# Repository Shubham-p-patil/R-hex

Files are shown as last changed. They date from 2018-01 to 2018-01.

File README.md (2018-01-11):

# R-hex
Negotiating difficult terrains has always been a challenging task for wheeled robots. To solve this issue, man has been trying to design various legged robots, taking inspiration from nature. Out of all these legged robots, six legged robots are the most common ones, since 6 legs have an edge over other legged robots considering their stability. In hexapods, generally a tripod gait is in used in which 2 sets of legs(3 each ) are alternatively on the ground. This hexapod is our attempt to tackle the same issue of all terrain driving capabilities. Instead of normal legs we have used C-shaped legs which have an added advantage of climbing obstacles, pretty taller than itself.

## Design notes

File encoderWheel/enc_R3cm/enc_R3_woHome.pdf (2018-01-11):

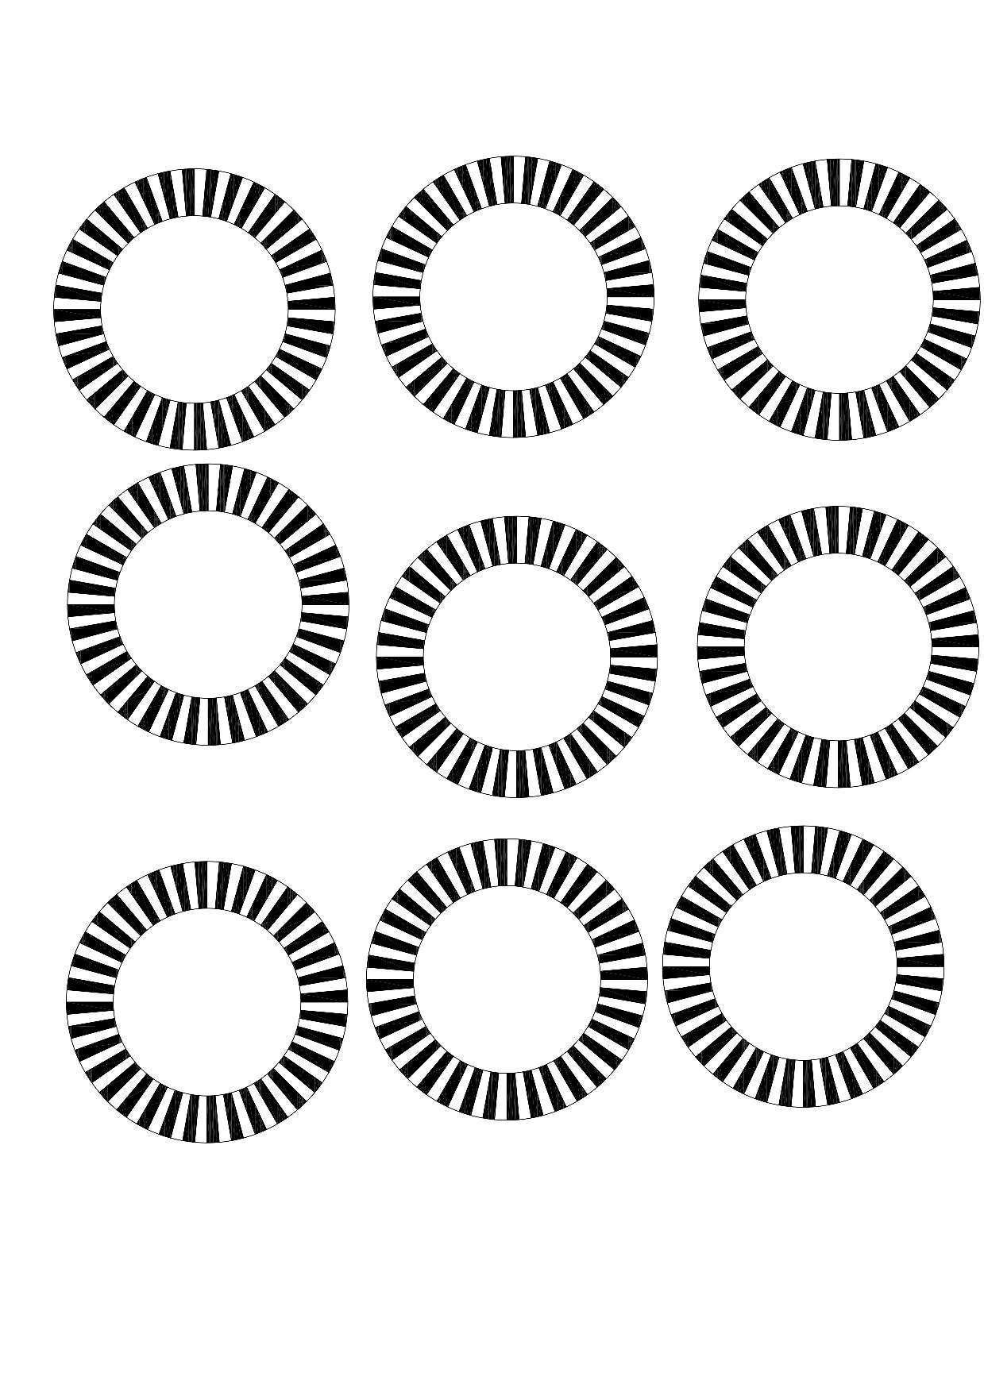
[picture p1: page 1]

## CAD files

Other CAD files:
encoderWheel/enc_R2.5cm/enc_R2.5_wHome.dwg
encoderWheel/enc_R3cm/enc_R3_wHome.dwg
encoderWheel/newR2.5/newR2.5.dwg

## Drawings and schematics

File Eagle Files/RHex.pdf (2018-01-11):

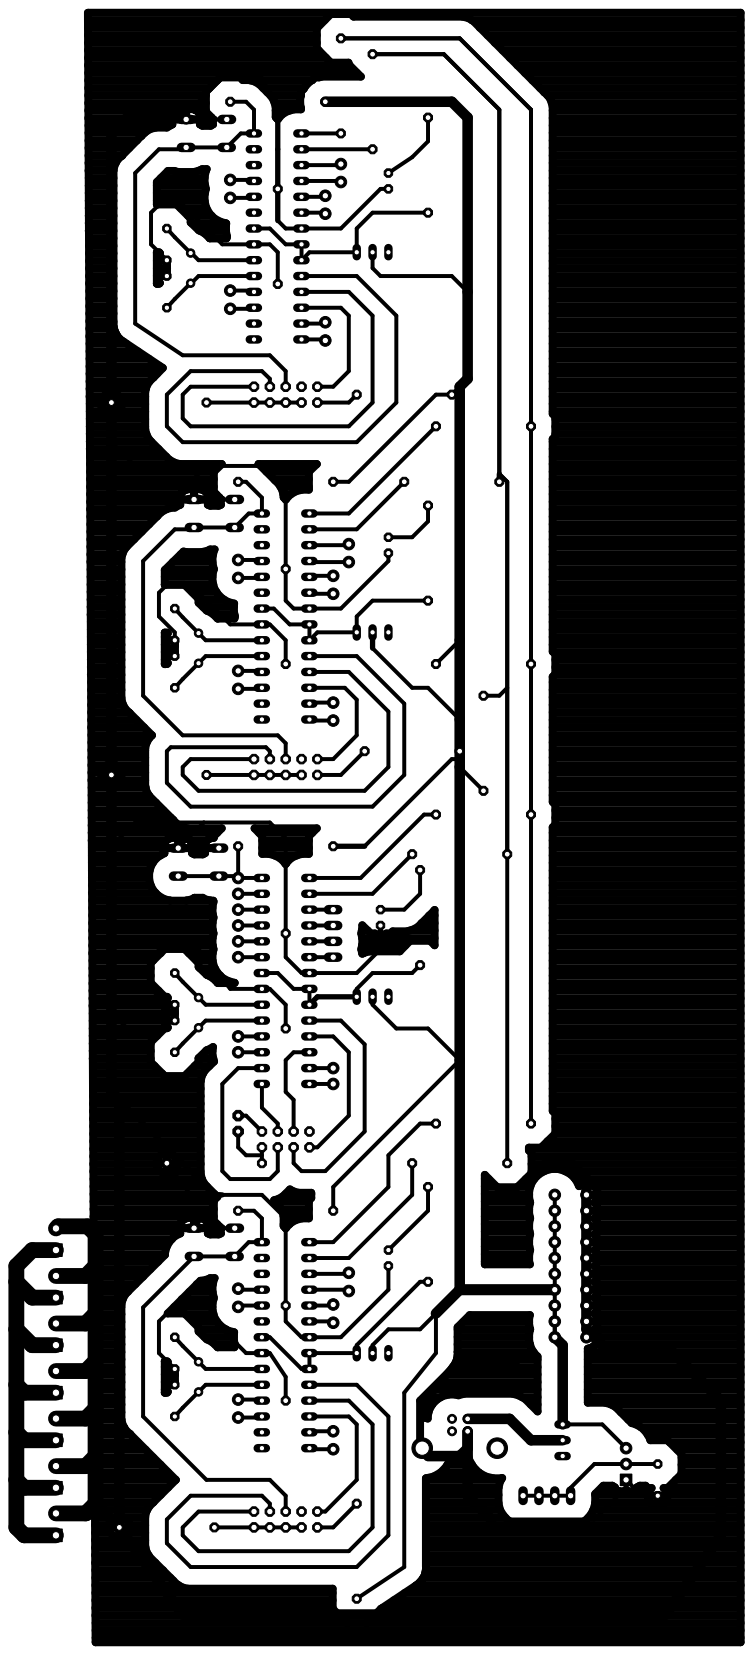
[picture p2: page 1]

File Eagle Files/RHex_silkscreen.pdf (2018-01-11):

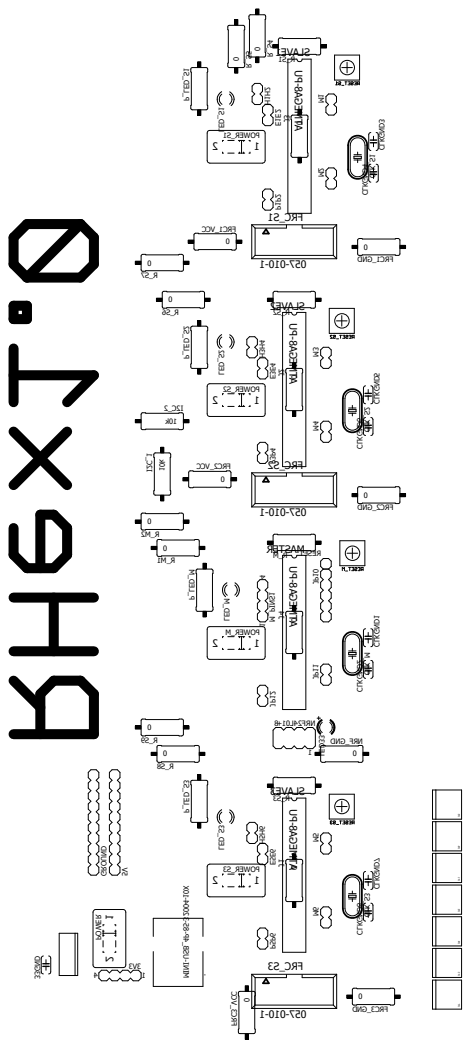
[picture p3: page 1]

057-010-1 ATMEGA8-PU ATMEGA8-PU ATMEGA8-PU ATMEGA8-PU MINI-USB_4P-85-32004-10X 0 0 0 0 0 0 0 0 0 0 0 0 0 0 0 0 0 0 0 10k

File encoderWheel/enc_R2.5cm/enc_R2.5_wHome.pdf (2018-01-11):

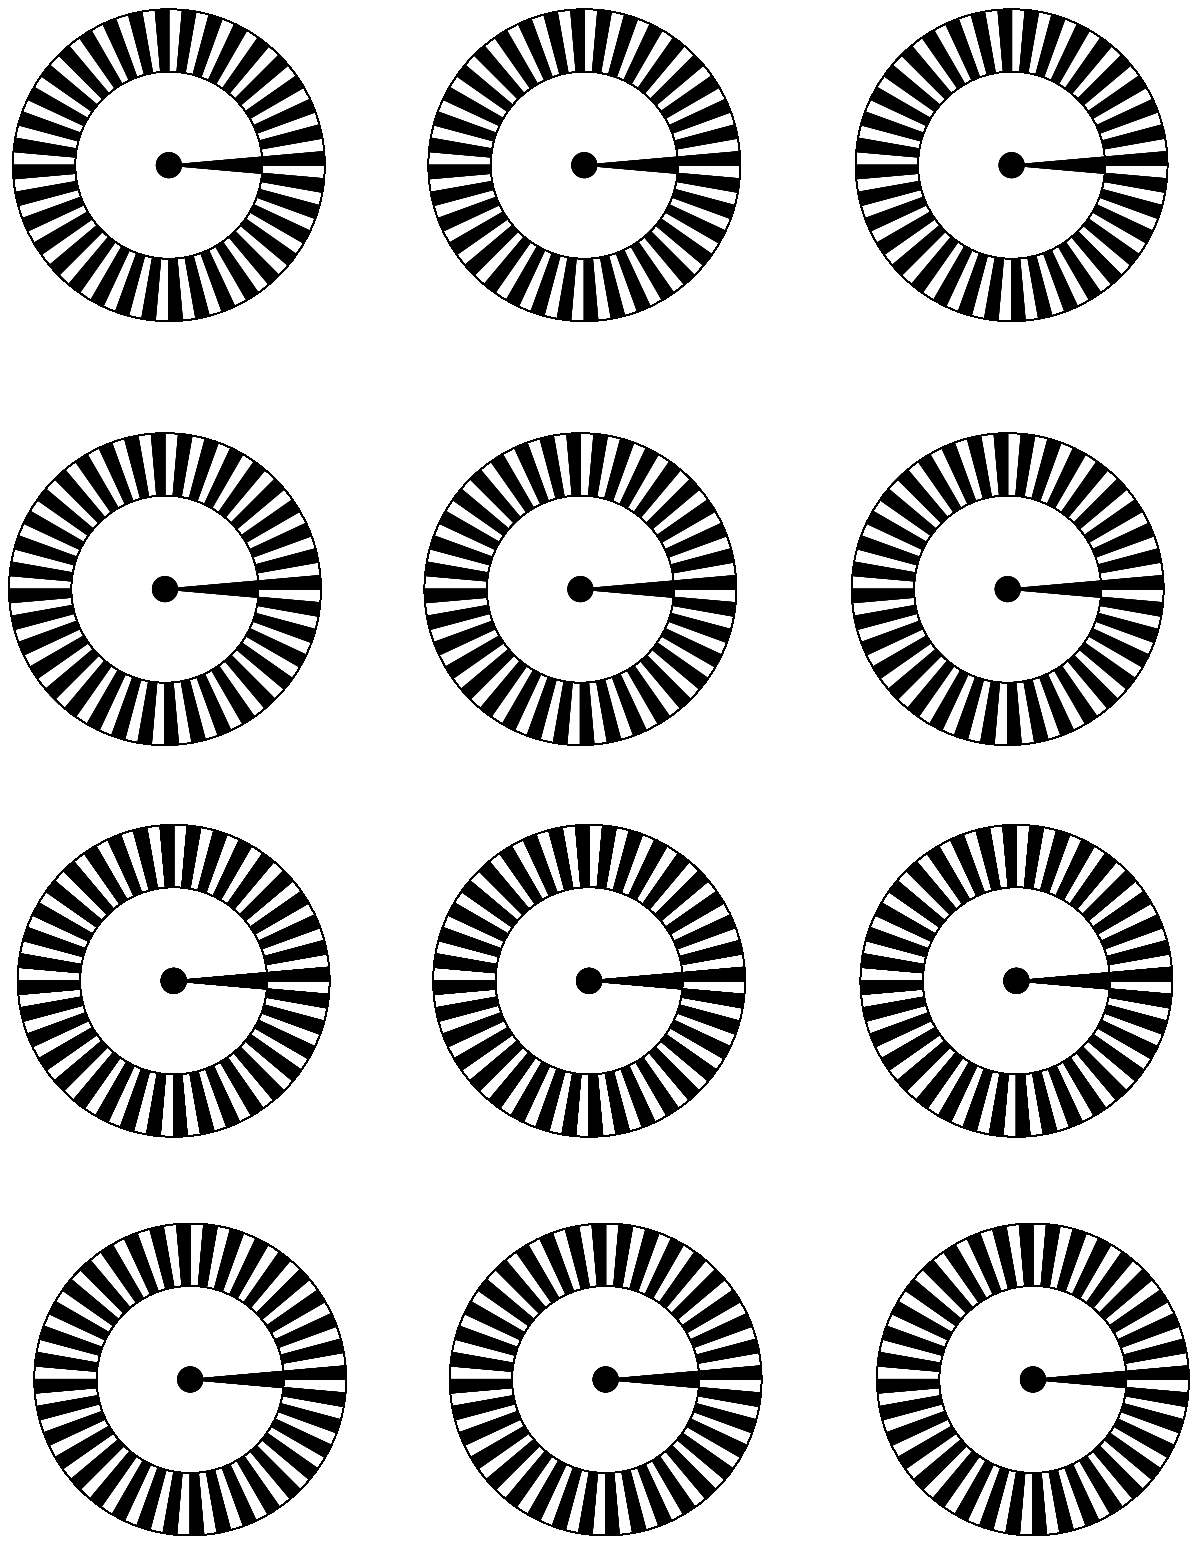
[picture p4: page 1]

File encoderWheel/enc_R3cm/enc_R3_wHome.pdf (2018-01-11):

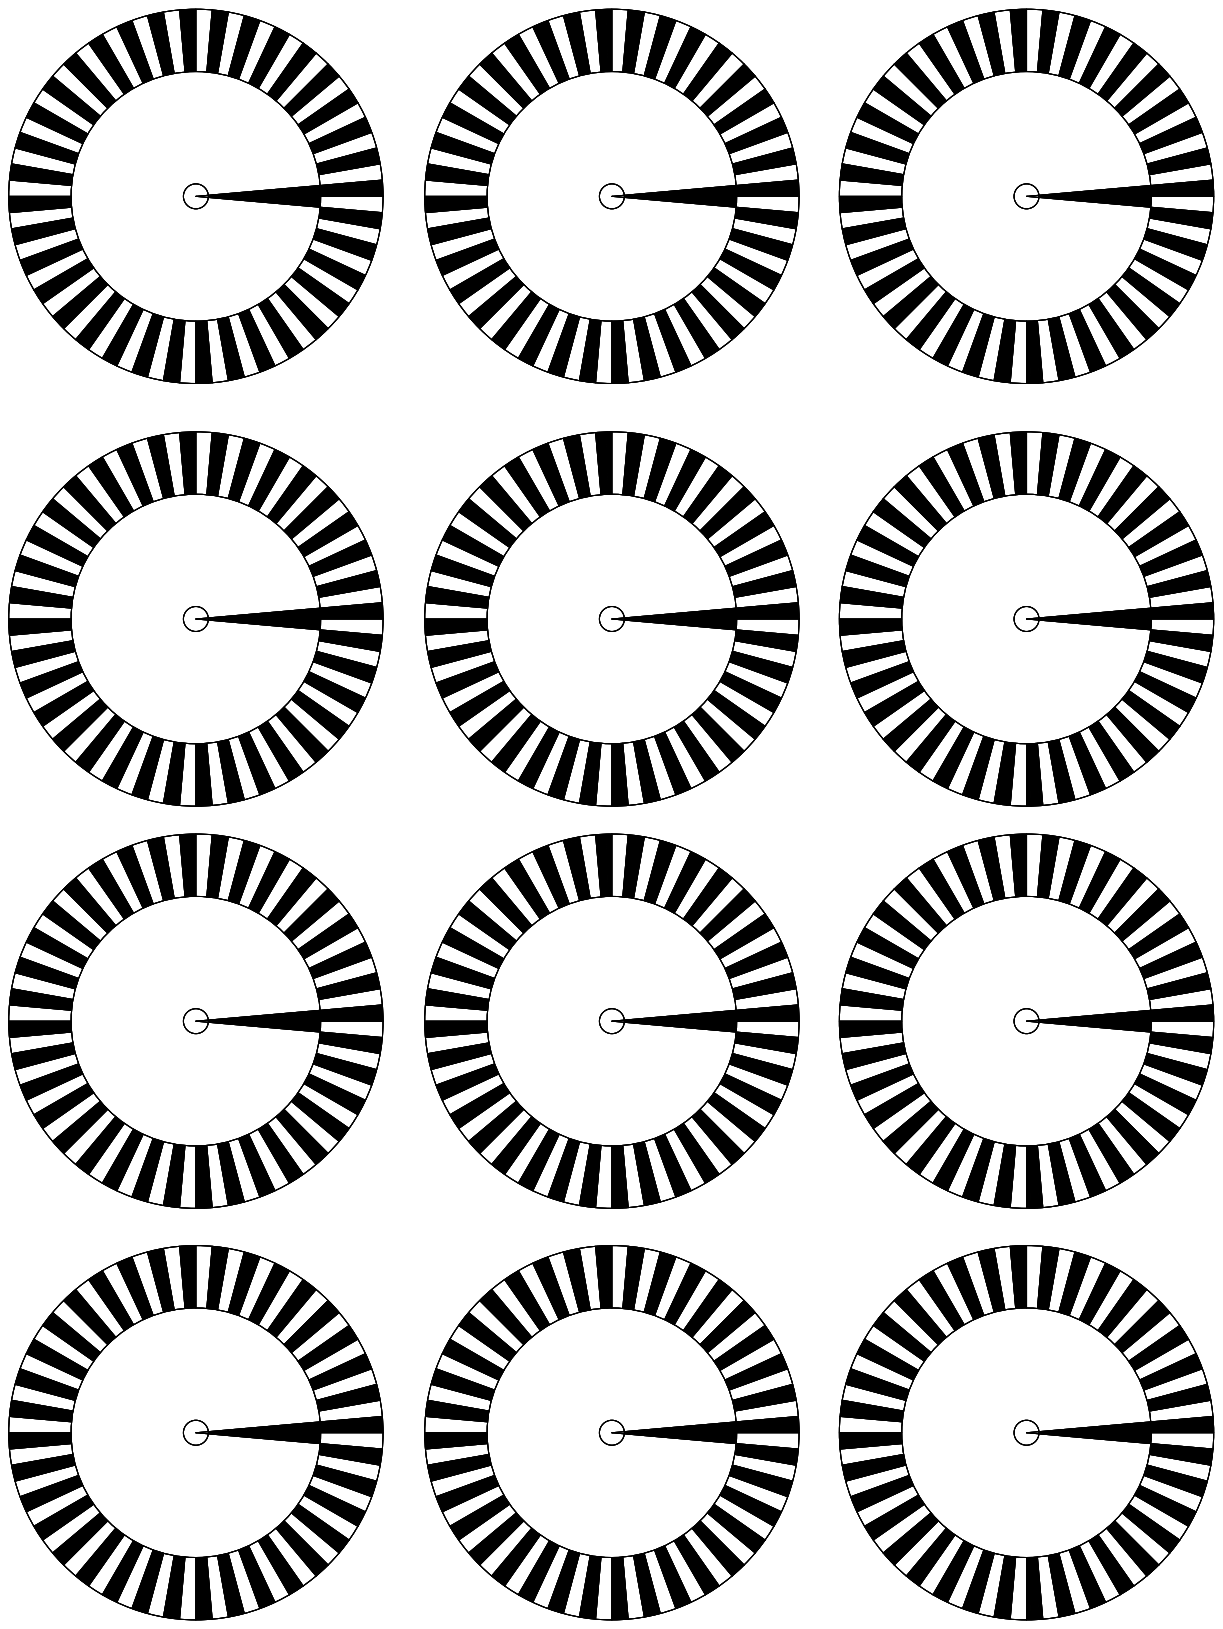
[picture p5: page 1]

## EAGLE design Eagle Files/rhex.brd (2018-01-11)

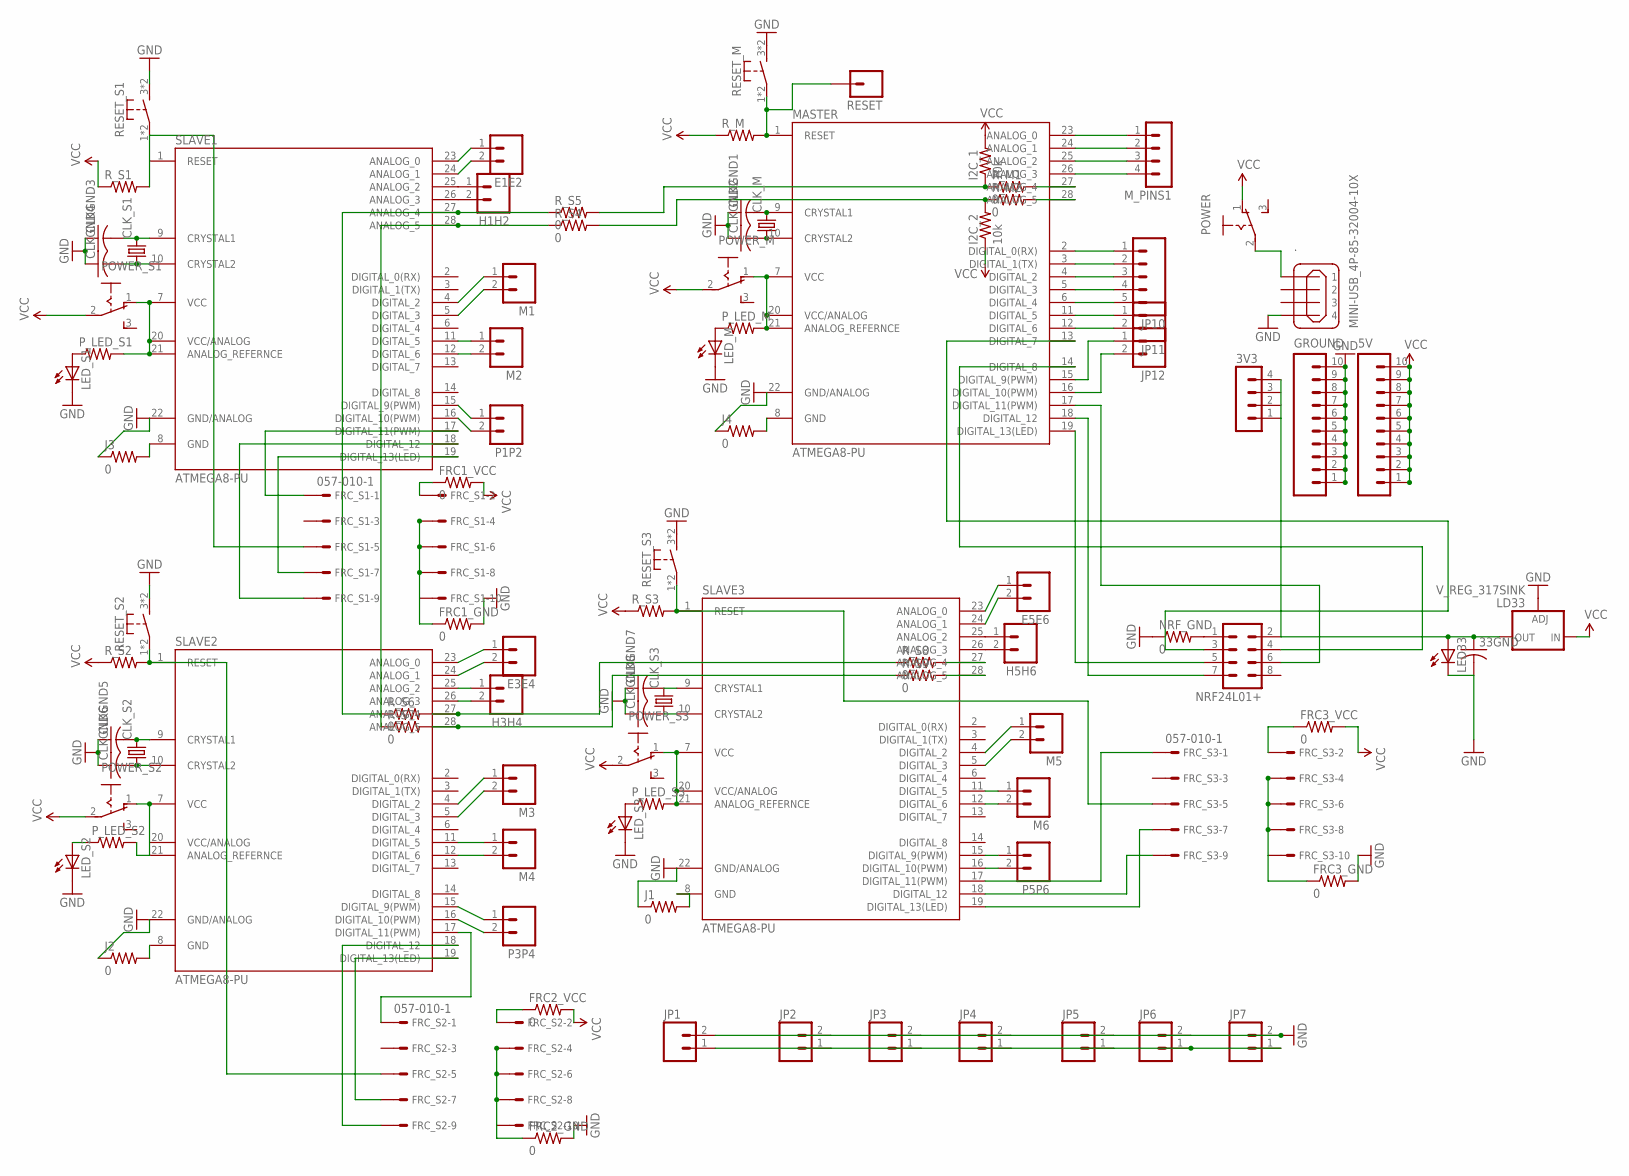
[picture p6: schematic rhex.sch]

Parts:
3V3: MA04-1
5V: M10SILK_FEMALE_PTH; 1X10
33GND: C-US050-024X044; C050-024X044
.: MINI-USB_4P-85-32004-10X; 85-32004-10X
CLKGND1, CLKGND2, CLKGND3, CLKGND4, CLKGND5, CLKGND6, CLKGND7, CLKGND8: C-US050-024X044; C050-024X044
CLK_M: CRYSTALHC49U-V; HC49U-V
CLK_S1, CLK_S2, CLK_S3: CRYSTALHC49U-V; HC49U-V
E1E2, E3E4, E5E6: M02LOCK; 1X02_LOCK
FRC1_GND, FRC1_VCC, FRC2_GND, FRC2_VCC, FRC3_GND, FRC3_VCC: 0; 0411/15
FRC_S1, FRC_S2, FRC_S3: 057-010-1
GROUND: M10SILK_FEMALE_PTH; 1X10
H1H2, H3H4, H5H6: M02LOCK; 1X02_LOCK
I2C_1, I2C_2: 10k; 0411/15
J1, J2, J3, J4: 0; 0411/15
JP1, JP2, JP3, JP4, JP5, JP6, JP7: M023.5MM; SCREWTERMINAL-3.5MM-2
JP10: M05PTH; 1X05
JP11, JP12: M02PTH; 1X02
LD33: V_REG_317SINK; TO220-ADJ
LED33: LED3MM
LED_M: LED3MM
LED_S1, LED_S2, LED_S3: LED3MM
M1, M2, M3, M4, M5, M6: M02LOCK; 1X02_LOCK
MASTER: ATMEGA8-PU; DIL28-3
M_PINS1: MA04-1
NRF24L01+: MA04-2
NRF_GND: 0; 0411/15
P1P2, P3P4, P5P6: M02LOCK; 1X02_LOCK
POWER: M251
POWER_M: M251
POWER_S1, POWER_S2, POWER_S3: M251
P_LED_M: R-US_0411/15; 0411/15
P_LED_S1, P_LED_S2, P_LED_S3: R-US_0411/15; 0411/15
RESET: M01PTH; 1X01
RESET_M: SW-TACTILE-6X6; SW6X6
RESET_S1, RESET_S2, RESET_S3: SW-TACTILE-6X6; SW6X6
R_M: R-US_0411/15; 0411/15
R_M1, R_M2: 0; 0411/15
R_S1, R_S2, R_S3: R-US_0411/15; 0411/15
R_S4, R_S5, R_S6, R_S7, R_S8, R_S9: 0; 0411/15
SLAVE1, SLAVE2, SLAVE3: ATMEGA8-PU; DIL28-3

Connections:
3V3: 3V3.1, 3V3.4, 33GND.1, LD33.OUT, LED33.A, NRF24L01+.2
12V: JP1.1, JP2.1, JP3.1, JP4.1, JP5.1, JP6.1, JP7.1
GND: 33GND.2, ..4, CLKGND1.1, CLKGND2.1, CLKGND3.1, CLKGND4.1, CLKGND5.1, CLKGND6.1, CLKGND7.1, CLKGND8.1, FRC1_GND.2, FRC2_GND.2, FRC3_GND.2, GROUND.1, GROUND.2, GROUND.3, GROUND.4, GROUND.5, GROUND.6, GROUND.7, GROUND.8, GROUND.9, GROUND.10, J1.1, J2.1, J3.1, J4.1, JP1.2, JP2.2, JP3.2, JP4.2, JP5.2, JP6.2, JP7.2, LD33.ADJ, LED33.K (C), LED_M.K (C), LED_S1.K (C), LED_S2.K (C), LED_S3.K (C), MASTER.22 (GND/ANALOG), NRF_GND.1, RESET_M.3 (S1), RESET_M.4 (S1), RESET_S1.3 (S1), RESET_S1.4 (S1), RESET_S2.3 (S1), RESET_S2.4 (S1), RESET_S3.3 (S1), RESET_S3.4 (S1), SLAVE1.22 (GND/ANALOG), SLAVE2.22 (GND/ANALOG), SLAVE3.22 (GND/ANALOG)
unnamed: CLKGND1.2, CLK_M.2, MASTER.9 (CRYSTAL1)
unnamed: CLKGND2.2, CLK_M.1, MASTER.10 (CRYSTAL2)
unnamed: MASTER.1 (RESET), RESET.1, RESET_M.1, RESET_M.2 (P1), R_M.2
unnamed: FRC_S2.1, SLAVE2.17 (DIGITAL_11(PWM))
unnamed: FRC_S3.5, RESET_S3.1, RESET_S3.2 (P1), R_S3.2, SLAVE3.1 (RESET)
unnamed: FRC_S2.5, RESET_S2.1, RESET_S2.2 (P1), R_S2.2, SLAVE2.1 (RESET)
unnamed: M3.1, SLAVE2.4 (DIGITAL_2)
unnamed: MASTER.19 (DIGITAL_13(LED)), NRF24L01+.5
unnamed: MASTER.18 (DIGITAL_12), NRF24L01+.7
unnamed: MASTER.17 (DIGITAL_11(PWM)), NRF24L01+.6
unnamed: R_S5.1, R_S6.1, SLAVE1.27 (ANALOG_4)
unnamed: R_S4.1, R_S7.1, SLAVE1.28 (ANALOG_5)
unnamed: M1.1, SLAVE1.4 (DIGITAL_2)
unnamed: M1.2, SLAVE1.5 (DIGITAL_3)
unnamed: M3.2, SLAVE2.5 (DIGITAL_3)
unnamed: M5.1, SLAVE3.4 (DIGITAL_2)
unnamed: M2.1, SLAVE1.11 (DIGITAL_5)
unnamed: MASTER.13 (DIGITAL_7), NRF24L01+.3
unnamed: M5.2, SLAVE3.5 (DIGITAL_3)
unnamed: M4.1, SLAVE2.11 (DIGITAL_5)
unnamed: M4.2, SLAVE2.12 (DIGITAL_6)
unnamed: M6.1, SLAVE3.11 (DIGITAL_5)
unnamed: M6.2, SLAVE3.12 (DIGITAL_6)
unnamed: M2.2, SLAVE1.12 (DIGITAL_6)
unnamed: JP10.1, MASTER.2 (DIGITAL_0(RX))
unnamed: I2C_2.2, R_M2.1, R_S4.2
unnamed: NRF24L01+.1, NRF_GND.2
unnamed: FRC_S2.7, SLAVE2.19 (DIGITAL_13(LED))
unnamed: E1E2.1, SLAVE1.23 (ANALOG_0)
unnamed: E1E2.2, SLAVE1.24 (ANALOG_1)
unnamed: E3E4.1, SLAVE2.23 (ANALOG_0)
unnamed: E3E4.2, SLAVE2.24 (ANALOG_1)
unnamed: E5E6.1, SLAVE3.23 (ANALOG_0)
unnamed: E5E6.2, SLAVE3.24 (ANALOG_1)
unnamed: CLKGND3.2, CLK_S1.2, SLAVE1.9 (CRYSTAL1)
unnamed: CLKGND4.2, CLK_S1.1, SLAVE1.10 (CRYSTAL2)
unnamed: CLKGND5.2, CLK_S2.2, SLAVE2.9 (CRYSTAL1)
unnamed: P3P4.1, SLAVE2.15 (DIGITAL_9(PWM))
unnamed: P3P4.2, SLAVE2.16 (DIGITAL_10(PWM))
unnamed: CLKGND6.2, CLK_S2.1, SLAVE2.10 (CRYSTAL2)
unnamed: CLKGND7.2, CLK_S3.2, SLAVE3.9 (CRYSTAL1)
unnamed: CLKGND8.2, CLK_S3.1, SLAVE3.10 (CRYSTAL2)
unnamed: FRC_S2.9, SLAVE2.18 (DIGITAL_12)
unnamed: ..1, POWER.2
unnamed: FRC_S3.1, SLAVE3.17 (DIGITAL_11(PWM))
unnamed: POWER_S1.1 (O), P_LED_S1.2, SLAVE1.7 (VCC), SLAVE1.20 (VCC/ANALOG), SLAVE1.21 (ANALOG_REFERNCE)
unnamed: FRC_S3.7, SLAVE3.19 (DIGITAL_13(LED))
unnamed: FRC_S3.9, SLAVE3.18 (DIGITAL_12)
unnamed: FRC_S1.7, SLAVE1.19 (DIGITAL_13(LED))
unnamed: FRC_S1.9, SLAVE1.18 (DIGITAL_12)
unnamed: FRC_S1.1, SLAVE1.17 (DIGITAL_11(PWM))
unnamed: P1P2.1, SLAVE1.15 (DIGITAL_9(PWM))
unnamed: POWER_S2.1 (O), P_LED_S2.2, SLAVE2.7 (VCC), SLAVE2.20 (VCC/ANALOG), SLAVE2.21 (ANALOG_REFERNCE)
unnamed: MASTER.7 (VCC), MASTER.20 (VCC/ANALOG), MASTER.21 (ANALOG_REFERNCE), POWER_M.1 (O), P_LED_M.2
unnamed: POWER_S3.1 (O), P_LED_S3.2, SLAVE3.7 (VCC), SLAVE3.20 (VCC/ANALOG), SLAVE3.21 (ANALOG_REFERNCE)
unnamed: P1P2.2, SLAVE1.16 (DIGITAL_10(PWM))
unnamed: P5P6.1, SLAVE3.15 (DIGITAL_9(PWM))
unnamed: P5P6.2, SLAVE3.16 (DIGITAL_10(PWM))
unnamed: H5H6.1, SLAVE3.25 (ANALOG_2)
unnamed: H5H6.2, SLAVE3.26 (ANALOG_3)
unnamed: H1H2.1, SLAVE1.25 (ANALOG_2)
unnamed: H1H2.2, SLAVE1.26 (ANALOG_3)
unnamed: H3H4.1, SLAVE2.25 (ANALOG_2)
unnamed: H3H4.2, SLAVE2.26 (ANALOG_3)
unnamed: LED_S1.A, P_LED_S1.1
unnamed: LED_M.A, P_LED_M.1
unnamed: LED_S3.A, P_LED_S3.1
unnamed: FRC2_GND.1, FRC_S2.4, FRC_S2.6, FRC_S2.8, FRC_S2.10
unnamed: LED_S2.A, P_LED_S2.1
unnamed: JP10.2, MASTER.3 (DIGITAL_1(TX))
unnamed: JP10.3, MASTER.4 (DIGITAL_2)
unnamed: JP10.4, MASTER.5 (DIGITAL_3)
unnamed: JP10.5, MASTER.6 (DIGITAL_4)
unnamed: JP11.1, MASTER.11 (DIGITAL_5)
unnamed: JP11.2, MASTER.12 (DIGITAL_6)
unnamed: JP12.1, MASTER.15 (DIGITAL_9(PWM))
unnamed: JP12.2, MASTER.16 (DIGITAL_10(PWM))
unnamed: MASTER.14 (DIGITAL_8), NRF24L01+.4
unnamed: MASTER.23 (ANALOG_0), M_PINS1.1
unnamed: MASTER.24 (ANALOG_1), M_PINS1.2
unnamed: MASTER.25 (ANALOG_2), M_PINS1.3
unnamed: MASTER.26 (ANALOG_3), M_PINS1.4
unnamed: J1.2, SLAVE3.8 (GND)
unnamed: J2.2, SLAVE2.8 (GND)
unnamed: J3.2, SLAVE1.8 (GND)
unnamed: J4.2, MASTER.8 (GND)
unnamed: FRC1_GND.1, FRC_S1.4, FRC_S1.6, FRC_S1.8, FRC_S1.10
unnamed: FRC_S1.5, RESET_S1.1, RESET_S1.2 (P1), R_S1.2, SLAVE1.1 (RESET)
unnamed: FRC3_GND.1, FRC_S3.4, FRC_S3.6, FRC_S3.8, FRC_S3.10
unnamed: FRC1_VCC.1, FRC_S1.2
unnamed: FRC2_VCC.1, FRC_S2.2
unnamed: FRC3_VCC.1, FRC_S3.2
unnamed: I2C_1.1, R_M1.1, R_S5.2
unnamed: R_S6.2, R_S8.1, SLAVE2.27 (ANALOG_4)
unnamed: R_S7.2, R_S9.1, SLAVE2.28 (ANALOG_5)
unnamed: R_S8.2, SLAVE3.27 (ANALOG_4)
unnamed: R_S9.2, SLAVE3.28 (ANALOG_5)
unnamed: MASTER.27 (ANALOG_4), R_M1.2
unnamed: MASTER.28 (ANALOG_5), R_M2.2
VCC: 5V.1, 5V.2, 5V.3, 5V.4, 5V.5, 5V.6, 5V.7, 5V.8, 5V.9, 5V.10, FRC1_VCC.2, FRC2_VCC.2, FRC3_VCC.2, I2C_1.2, I2C_2.1, LD33.IN, POWER.1 (O), POWER_M.2, POWER_S1.2, POWER_S2.2, POWER_S3.2, R_M.1, R_S1.1, R_S2.1, R_S3.1

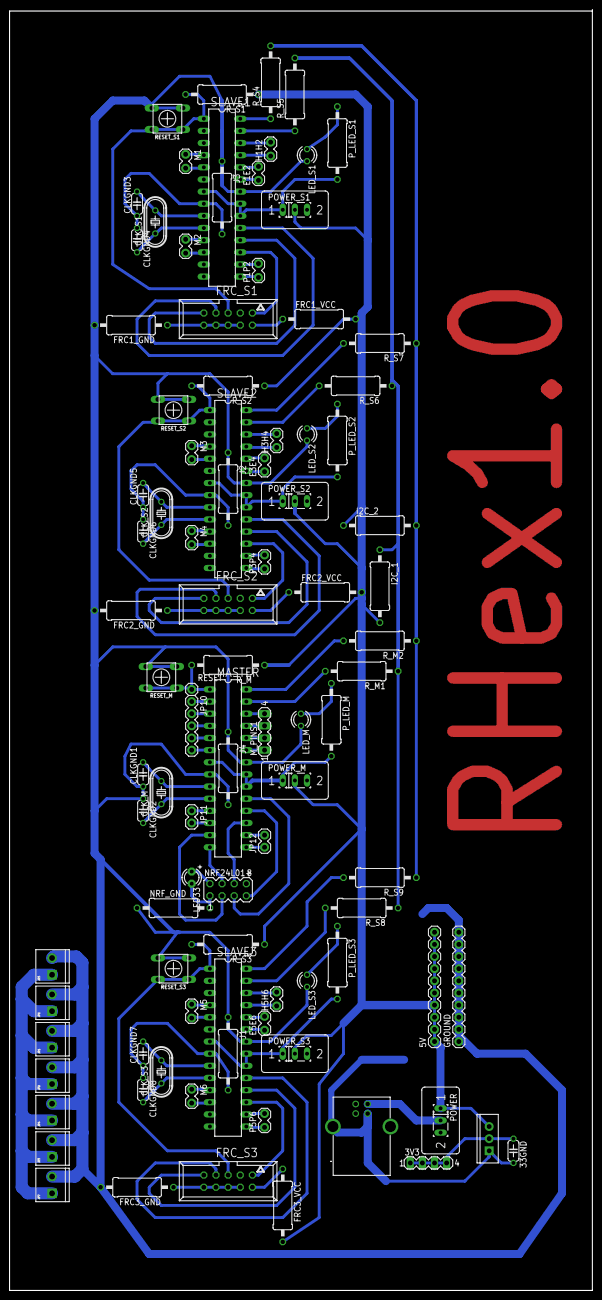
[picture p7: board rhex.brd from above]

Board: 2 copper layers, 121.9 x 267.9 mm, 96 parts (0 on the bottom side), 103 nets.

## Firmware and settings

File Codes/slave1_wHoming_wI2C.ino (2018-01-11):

# include<Wire.h>

int ePins[2] = {2,3}; 
int hPins[2] = {A2,A3};
int motor2Pins[2] = {A0,A1}; //Direction pin for left motor
int motor1Pins[2] = {5,6}; //Direction pin for right motor
int pwmPins[2] = {9,10}; //PWM pins for motor 1(left) and motor 2(right)

int count[2] = {0,0};  //Number of ticks to be rotated as instructed by master
int ticks[2] = {0,0}; //Actual encoder count of motor 1(left) and motor 2(right)
int newTicks[2]={0,0},oldTicks[2]={0,0},botMotion=1;
int magState[2] = {0,0};
int confirmation[2] = {1,1}; //0-Both done, 1-motor1done, 2-motor2done 3-none done
int encrypted_confirmation=0;s
int mSpeed[2]={0,0};
int hSpeed=150;

void setup() {
  pinMode(ePins[0],INPUT);
  pinMode(ePins[1],INPUT);
  pinMode(hPins[0],INPUT);
  pinMode(hPins[1],INPUT);
  pinMode(motor1Pins[0],OUTPUT);
  pinMode(motor1Pins[1],OUTPUT);
  pinMode(motor2Pins[0],OUTPUT);
  pinMode(motor2Pins[1],OUTPUT);
  pinMode(pwmPins[0],OUTPUT);
  pinMode(pwmPins[1],OUTPUT);
  
  Serial.begin(115200);
  
  Wire.begin(1);
  Wire.onReceive(receiveInfo);
  Wire.onRequest(sendConfirmation);
  
  homing();
}

void loop() {
  //Routine to check encoder states
  newTicks[0]= digitalRead(ePins[0]);
  newTicks[1]= digitalRead(ePins[1]);
  if (newTicks[0]!= oldTicks[0]) {
    ticks[0]++;
  }
  if (newTicks[1]!= oldTicks[1]) {
    ticks[1]++;
  }
 oldTicks[0] = newTicks[0];  
 oldTicks[1] = newTicks[1];  

 //Routine to check magneotmeter state
 magState[0] = analogRead(hPins[0]);
 magState[1] = analogRead(hPins[1]);
 if (magState[0]<400) {
  ticks[0] = 0;
 }
 if (magState[1]<400) {
  ticks[1] = 0;
 }
 
 if(count[0] != ticks[0] && confirmation[0] == 0) {
  motor1Drive(botMotion,mSpeed[0]);
 }
 else {
  confirmation[0]=1;
  motor1Stop();
  Serial.println("MOTOR 1 STOPPED");
 }
 
 if(count[1] != ticks[1] && confirmation[1] == 0) {
  motor2Drive(botMotion,mSpeed[1]);
 } 
 else {
  confirmation[1]=1;
  motor2Stop();
  Serial.println("MOTOR 2 STOPPED");
 }
// printSensorStats();

}


void sendConfirmation()
{
  if (confirmation[0] == 1 && confirmation[1] == 1) {
    encrypted_confirmation = 0;
  }
  if (confirmation[0] == 1 && confirmation[1] == 0) {
    encrypted_confirmation = 1;
  }
  if (confirmation[0] == 0 && confirmation[1] == 1) {
    encrypted_confirmation = 2;
  }
  if (confirmation[0] == 0 && confirmation[1] == 0) {
    encrypted_confirmation = 3;
  }
 Wire.write(encrypted_confirmation);
Serial.println(encrypted_confirmation);
// Serial.print(confirmation[0]);
// Serial.print("\t");
// Serial.println(confirmation[1]); 
// Serial.println("Confirmation sent succesfully!");
}

void receiveInfo(int num)
{
if(Wire.available()<=5)
  {
    count[0]=Wire.read();
    count[1]=Wire.read();
    mSpeed[0]=Wire.read();
    mSpeed[1]=Wire.read();
    botMotion=Wire.read();
//    Serial.print(count[0]);
//   Serial.print("\t");
//    Serial.print(count[1]);
//    Serial.print("\t");
//    Serial.print(mSpeed[0]);
//    Serial.print("\t");
//    Serial.print(mSpeed[1]);
//    Serial.print("\t");
//    Serial.println(botMotion);
  }
  confirmation[0] = 0;
  confirmation[1] = 0;  
  Serial.println("CONFIRMATIONS SET TO ZERO");
}

void motor1Drive(int x, int y)
{ 
  analogWrite(pwmPins[0],y);
  if(x==1)
  {
  digitalWrite(motor1Pins[0],HIGH);
  digitalWrite(motor1Pins[1],LOW); 
  }
  if(x==2)
  {
  digitalWrite(motor1Pins[0],LOW);
  digitalWrite(motor1Pins[1],HIGH); 
  }
  if(x==3)
  {
  digitalWrite(motor1Pins[0],HIGH);
  digitalWrite(motor1Pins[1],LOW); 
  }
  if(x==4)
  {
  digitalWrite(motor1Pins[0],LOW);
  digitalWrite(motor1Pins[1],HIGH); 
  }
}

void motor2Drive(int x,int y)
{ 
  analogWrite(pwmPins[1],y);
  if(x==1)
  {
  digitalWrite(motor2Pins[0],HIGH);
  digitalWrite(motor2Pins[1],LOW); 
  }
  if(x==2)
  {
  digitalWrite(motor2Pins[0],LOW);
  digitalWrite(motor2Pins[1],HIGH); 
  }
  if(x==3)
  {
  digitalWrite(motor2Pins[0],LOW);
  digitalWrite(motor2Pins[1],HIGH); 
  }
  if(x==4)
  {
  digitalWrite(motor2Pins[0],HIGH);
  digitalWrite(motor2Pins[1],LOW); 
  }
}

void motor1Stop()
{
  digitalWrite(motor1Pins[0],HIGH);
  digitalWrite(motor1Pins[1],HIGH);
  delay(2);
 }
 void motor2Stop()
{
  digitalWrite(motor2Pins[0],HIGH);
  digitalWrite(motor2Pins[1],HIGH);
  delay(2);
 }

void homing()
{
 int hState0= digitalRead(hPins[0]);
 int hState1= digitalRead(hPins[1]);
  while(hState0||hState1)
  {
    Serial.println("homing");
    if(hState0)
      {motor1Drive(1,hSpeed);}
    if(hState1)
      {motor2Drive(1,hSpeed);}
    hState0= digitalRead(hPins[0]);
    hState1= digitalRead(hPins[1]);
  }
  digitalWrite(motor1Pins[0],LOW);
  digitalWrite(motor1Pins[1],HIGH);
  digitalWrite(motor2Pins[0],LOW);
  digitalWrite(motor2Pins[1],HIGH);
  delay(5);
  digitalWrite(motor1Pins[0],HIGH);
  digitalWrite(motor1Pins[1],HIGH);
  digitalWrite(motor2Pins[0],HIGH);
  digitalWrite(motor2Pins[1],HIGH);
  delay(300);
}

void printSensorStats() {
// Serial.println(digitalRead(hPins[0]));
// Serial.println(" ");
// Serial.println(digitalRead(hPins[1]));
// Serial.println(" ");
// Serial.println(newTicks[0]);
// Serial.println(" ");
// Serial.println(newTicks[1]);
// Serial.println(" ");
 Serial.print(ticks[0]);
 Serial.print(" ");
 Serial.print(ticks[1]);
 Serial.print(" ");
Serial.println();
 }

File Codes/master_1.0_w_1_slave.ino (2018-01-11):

#include<Wire.h>
int confirmation[2]={0,0};
int recieved_confirmation = 0;
int air=52,ground=20;
int Home=0;
int mSpeed[2]={100,240}; //(groundSpeed,airSpeed)
int flag[2]={0,1};
int botMotion=1;

void setup() {
Serial.begin(115200);
Wire.begin();
}

void loop() {
while(1)
{
 receiveConfirmation();
 if(confirmation[0]==1&&confirmation[1]==1)
   {
    break;
   }
   Serial.print(flag[0]);
Serial.print("\t");
Serial.println(flag[1]);
}
setFlag();
//Serial.println("break");

if (flag[0]==1 && flag[1]==0)
  {
  slaveWrite(ground,air,mSpeed[0],mSpeed[1],botMotion,1);
  }
  
if (flag[0]==0&&flag[1]==1)
  {
  slaveWrite(air,ground,mSpeed[1],mSpeed[0],botMotion,1);
  }
 if (flag[0]==1&&flag[1]==1 || flag[0] == 0 && flag[1] == 0) {
  Serial.println("Both flags 1 or 0, you are fucked!");
 }
}

void receiveConfirmation()
{
 Wire.requestFrom(1,1);
   if(Wire.available()>0)
   {
   recieved_confirmation= Wire.read();
   switch(recieved_confirmation) {
    case 0:
      confirmation[0] =1;
      confirmation[1] =1;
      break;
    case 1:
      confirmation[0] =1;
      confirmation[1] =0;
      break;
    case 2:
      confirmation[0] =0;
      confirmation[1] =1;
      break;
    case 3:
      confirmation[0] =0;
      confirmation[1] =0;
      break;
   }
   Serial.println(recieved_confirmation);
//   Serial.print(confirmation[0]);
//   Serial.print("\t");
//   Serial.println(confirmation[1]);
   }
}

void setFlag()
{
  //Serial.println("set flag");
  if(confirmation[0] == 1) {
    if (flag[0] == 0) {
      flag[0] =1;
    } else {
      flag[0] = 0;
    }
   // Serial.println("changing flag");  
  }
  if(confirmation[1] == 1) {
    if (flag[1] == 0) {
      flag[1] =1;
    } else {
      flag[1] = 0;
    }
   // Serial.println("changing flag");  
  }
}

void slaveWrite(int a,int b,int c,int d,int e,int f)
{
Wire.beginTransmission(f);
Serial.println("slave writing started");
Wire.write(a);
Wire.write(b);
Wire.write(c);
Wire.write(d);
Wire.write(e);
Wire.endTransmission();
Serial.println("slave write done");
}

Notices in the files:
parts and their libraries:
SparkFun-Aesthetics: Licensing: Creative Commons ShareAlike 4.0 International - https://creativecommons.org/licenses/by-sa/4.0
